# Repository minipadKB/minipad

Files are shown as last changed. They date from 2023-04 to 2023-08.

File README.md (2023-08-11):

<div align="center">

# minipad






The PCB and case files for the minipad, an RP2040-based 2-3-key keypad for the rhythm game osu!.

This hardware is designed specifically to work with our open-source firmware,</br>
which can be found in our GitHub repository [here](https://github.com/minipadkb/minipad-firmware).

</div>

<div align="center">
<i>Made with ❤️ by Project Minipad</i>
</div>

# Which file should I download?

Head over to the [releases section](https://github.com/minipadKB/minipad/releases/latest). There, you can find the latest release and it's `Case.zip` and `PCB.zip` files. Download and extract them and you'll see a `2k` and `3k` folder in each archive. Depending on your desired amount of keys, use the files in that folder.

# Project Structure

The root folder of this repository is split into two folders, `Latest` and `Older Versions`. It is advised to only use the latest files.</br>
`Latest` contains the files for the newest version of the minipad PCB and Case.</br>
`Older Versions` contains a number of folders representing older releases of the PCBs and Cases.

Inside each versions folder you can find a `PCB` folder, containing a `2k` and `3k` folder for the two variants of the keypad, and a `Case` folder, containing the .stl files for the 3D-print.

If you are unsure about what to do or you're having any questions, feel free to join our [Discord](https://discord.gg/minipad)!

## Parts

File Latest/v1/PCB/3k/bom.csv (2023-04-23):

Comment | Designator | Footprint | LCSC
1k | R1,R4,R7 | R_0402_1005Metric | C11702
500mA | F1 | Fuse_0402_1005Metric | C136320
100nF | C11,C12,C13,C14,C15,C16,C17,C5,C7,C8 | C_0402_1005Metric | C1525
10uF | C9 | C_0402_1005Metric | C15525
20pF | C3,C4 | C_0402_1005Metric | C1554
USB_C_12P | USB1 | USB_C_Receptacle_HRO_TYPE-C-31-M-12 | C165948
RP2040 | U1 | RP2040-QFN-56 | C2040
27 | R2,R3 | R_0603_1608Metric | C25190
5.1k | R5,R6 | R_0402_1005Metric | C25905
Hall_Sensor | K1,K2,K3 | SOT-23 | C2904393
1uF | C1,C10,C2,C6 | C_0402_1005Metric | C52923
XC6206PxxxMR | U3 | SOT-23 | C5446
SRV05-4 | U2 | SOT-23-6-routable | C85364
12MHZ | Y1 | Crystal_SMD_3225-4Pin_3.2x2.5mm | C9002
W25Q128JVS | U4 | SOIC-8_5.23x5.23mm_P1.27mm | C97521

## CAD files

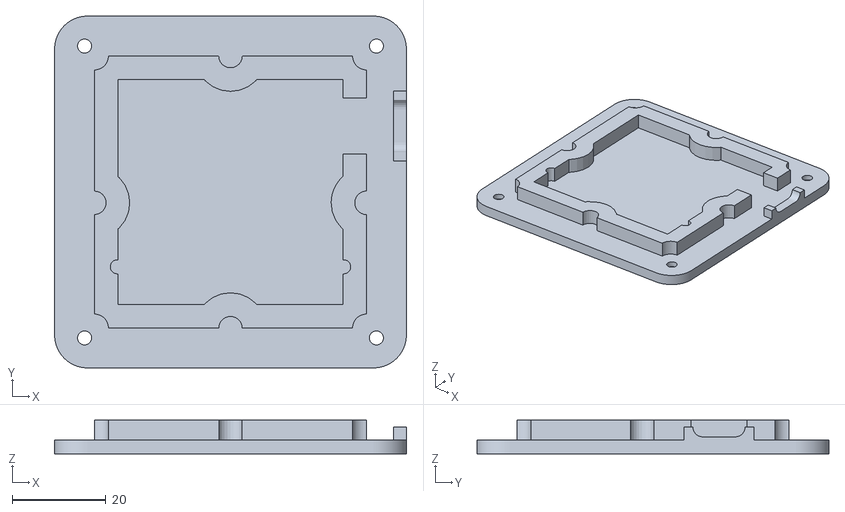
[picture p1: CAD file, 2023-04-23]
Latest/v1/Case/3k/bottom.stl
75.0 x 75.0 x 7.20

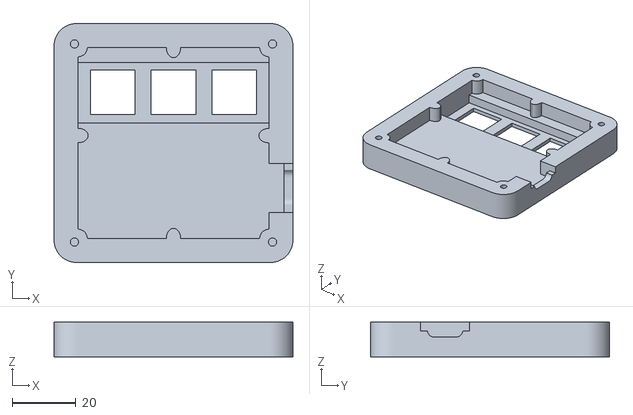
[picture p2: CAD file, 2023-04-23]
Latest/v1/Case/3k/top.stl
75.0 x 75.0 x 10.9

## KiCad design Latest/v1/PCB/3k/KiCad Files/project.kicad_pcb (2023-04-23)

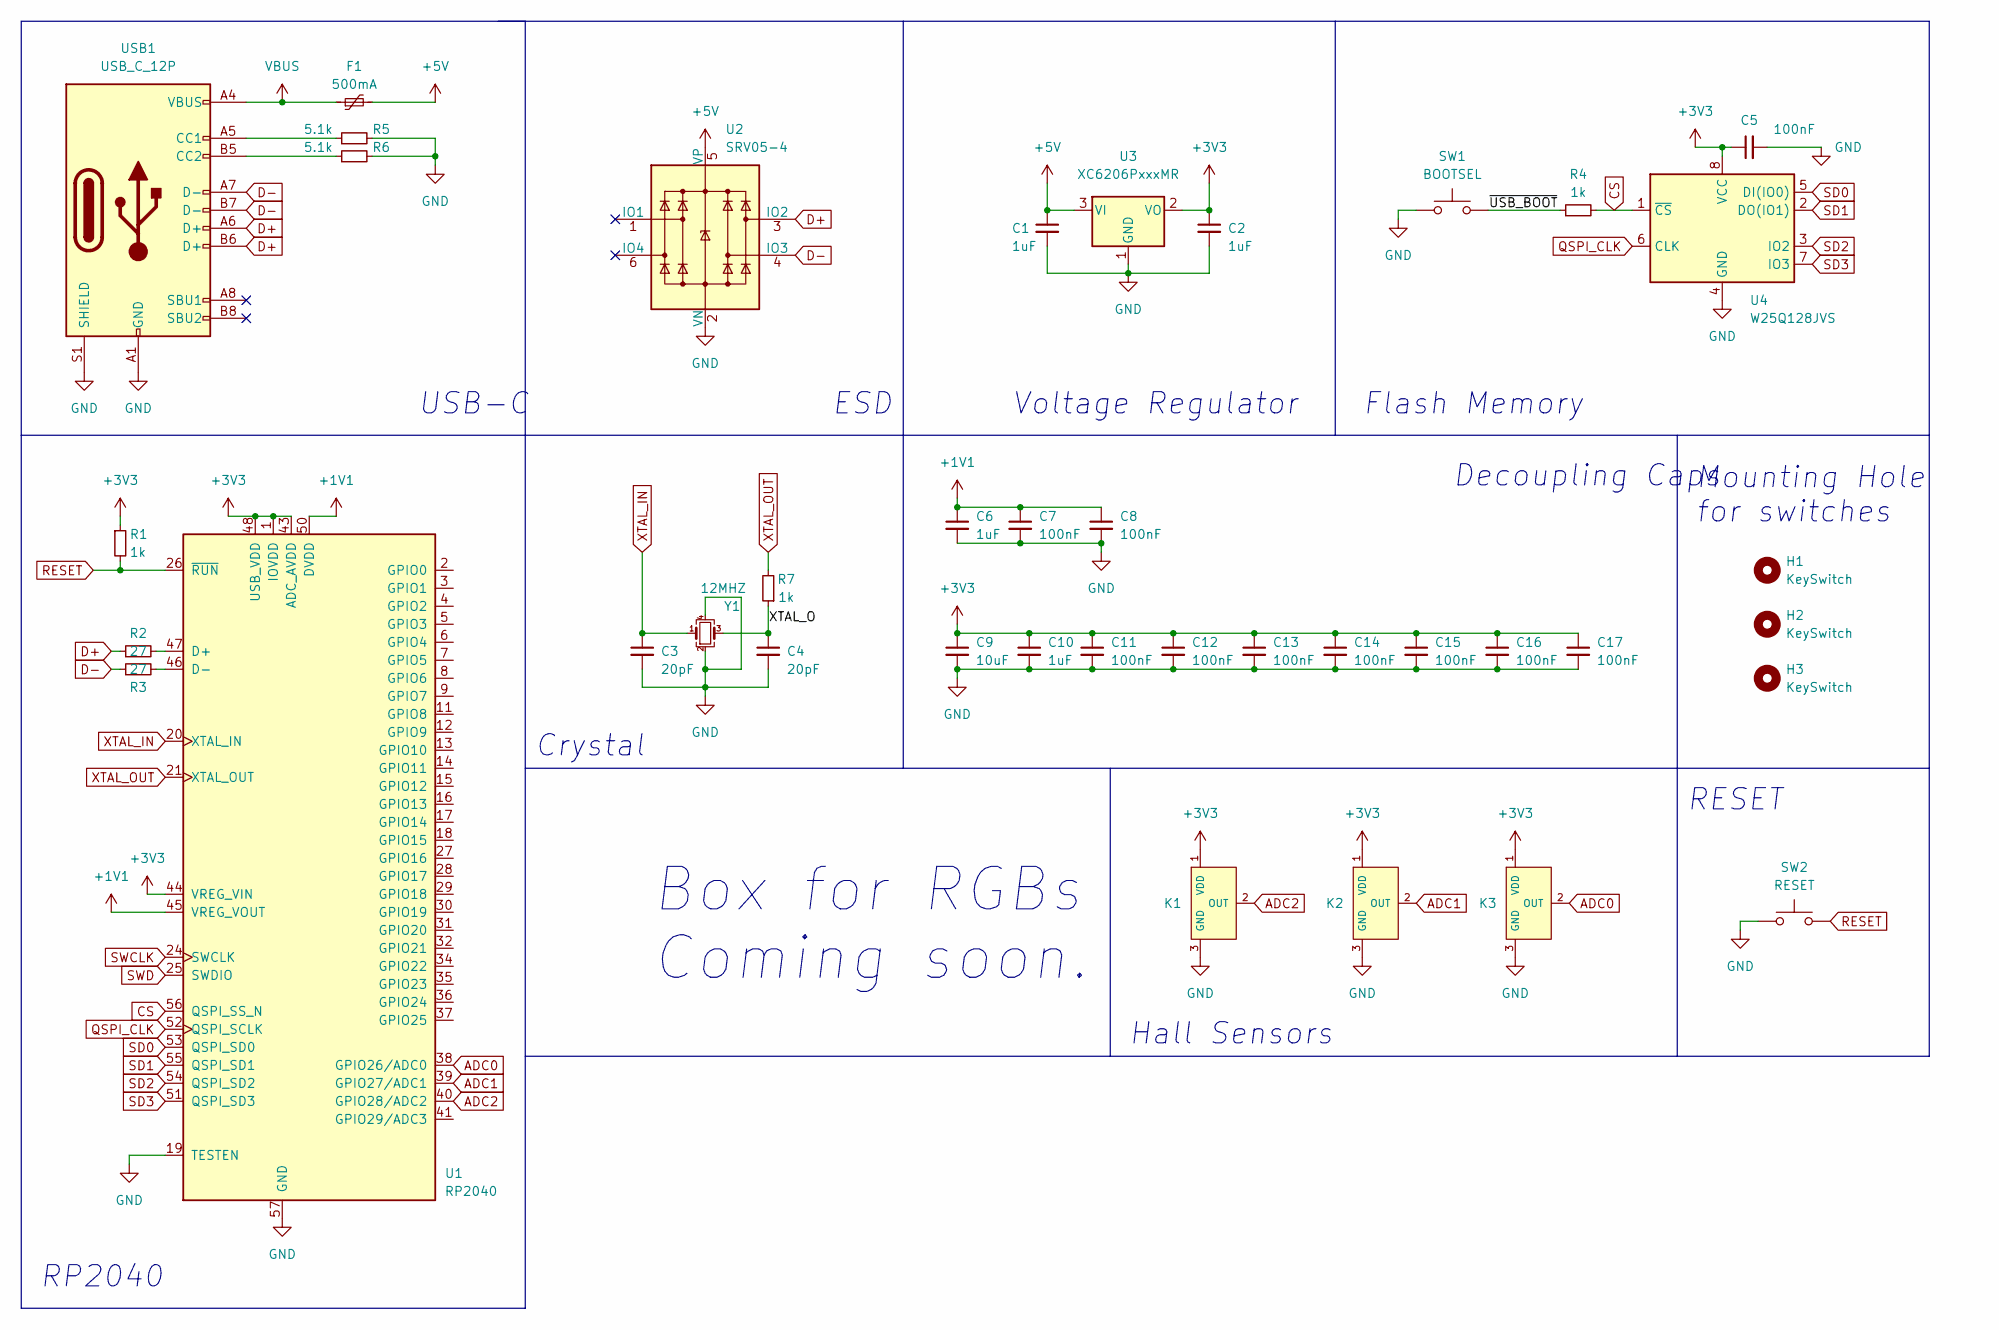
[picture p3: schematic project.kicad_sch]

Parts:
C1, C2, C6, C10: 1uF; C_0402_1005Metric
C3, C4: 20pF; C_0402_1005Metric
C5, C7, C8, C11, C12, C13, C14, C15, C16, C17: 100nF; C_0402_1005Metric
C9: 10uF; C_0402_1005Metric
F1: 500mA; Fuse_0402_1005Metric
H1, H2, H3: KeySwitch; MXOnly-1U-FLIPPED
K1, K2, K3: Hall_Sensor; SOT-23; MPN GH39FKSW; LCSC Part C266230
R1, R4, R7: 1k; R_0402_1005Metric
R2, R3: 27; R_0603_1608Metric
R5, R6: 5.1k; R_0402_1005Metric
SW1: BOOTSEL; SolderJumper-2_P1.3mm_Open_RoundedPad1.0x1.5mm
SW2: RESET; SolderJumper-2_P1.3mm_Open_RoundedPad1.0x1.5mm
U1: RP2040; RP2040-QFN-56
U2: SRV05-4; SOT-23-6-routable
U3: XC6206PxxxMR; SOT-23
U4: W25Q128JVS; SOIC-8_5.23x5.23mm_P1.27mm
USB1: USB_C_12P; USB_C_Receptacle_HRO_TYPE-C-31-M-12
Y1: 12MHZ; Crystal_SMD_3225-4Pin_3.2x2.5mm

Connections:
+1V1: C6.1, C7.1, C8.1, U1.23 (DVDD), U1.45 (VREG_VOUT), U1.50 (DVDD)
+3V3: C2.1, C5.1, C9.1, C10.1, C11.1, C12.1, C13.1, C14.1, C15.1, C16.1, C17.1, K1.1 (VDD), K2.1 (VDD), K3.1 (VDD), R1.1, U1.1 (IOVDD), U1.10 (IOVDD), U1.22 (IOVDD), U1.33 (IOVDD), U1.42 (IOVDD), U1.43 (ADC_AVDD), U1.44 (VREG_VIN), U1.48 (USB_VDD), U1.49 (IOVDD), U3.2 (VO), U4.8 (VCC)
+5V: C1.1, F1.2, U2.5 (VP), U3.3 (VI)
/XTAL_O: C4.1, R7.1, Y1.3
/~USB_BOOT: R4.1, SW1.2
ADC0: K3.2 (OUT), U1.38 (GPIO26/ADC0)
ADC1: K2.2 (OUT), U1.39 (GPIO27/ADC1)
ADC2: K1.2 (OUT), U1.40 (GPIO28/ADC2)
CS: R4.2, U1.56 (QSPI_SS_N), U4.1 (~CS)
D+: R2.1, U2.3 (IO2), USB1.A6 (D+), USB1.B6 (D+)
D-: R3.1, U2.4 (IO3), USB1.A7 (D-), USB1.B7 (D-)
GND: C1.2, C2.2, C3.2, C4.2, C5.2, C6.2, C7.2, C8.2, C9.2, C10.2, C11.2, C12.2, C13.2, C14.2, C15.2, C16.2, C17.2, K1.3 (GND), K2.3 (GND), K3.3 (GND), R5.2, R6.2, SW1.1, SW2.1, U1.19 (TESTEN), U1.57 (GND), U2.2 (VN), U3.1 (GND), U4.4 (GND), USB1.A1 (GND), USB1.A12 (GND), USB1.B1 (GND), USB1.B12 (GND), USB1.S1 (SHIELD), Y1.2, Y1.4
unnamed: R2.2, U1.47 (D+)
unnamed: R3.2, U1.46 (D-)
unnamed: R5.1, USB1.A5 (CC1)
unnamed: R6.1, USB1.B5 (CC2)
QSPI_CLK: U1.52 (QSPI_SCLK), U4.6 (CLK)
RESET: R1.2, SW2.2, U1.26 (~RUN)
RGB: U1.41 (GPIO29/ADC3)
SD0: U1.53 (QSPI_SD0), U4.5 (DI(IO0))
SD1: U1.55 (QSPI_SD1), U4.2 (DO(IO1))
SD2: U1.54 (QSPI_SD2), U4.3 (IO2)
SD3: U1.51 (QSPI_SD3), U4.7 (IO3)
SWCLK: U1.24 (SWCLK)
SWD: U1.25 (SWDIO)
VBUS: F1.1, USB1.A4 (VBUS), USB1.A9 (VBUS), USB1.B4 (VBUS), USB1.B9 (VBUS)
XTAL_IN: C3.1, U1.20 (XTAL_IN), Y1.1
XTAL_OUT: R7.2, U1.21 (XTAL_OUT)

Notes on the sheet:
Decoupling Caps
RESET
Box for RGBs Coming soon.
Voltage Regulator
ESD
RP2040
Hall Sensors
USB-C
Mounting Hole for switches
Crystal
Flash Memory

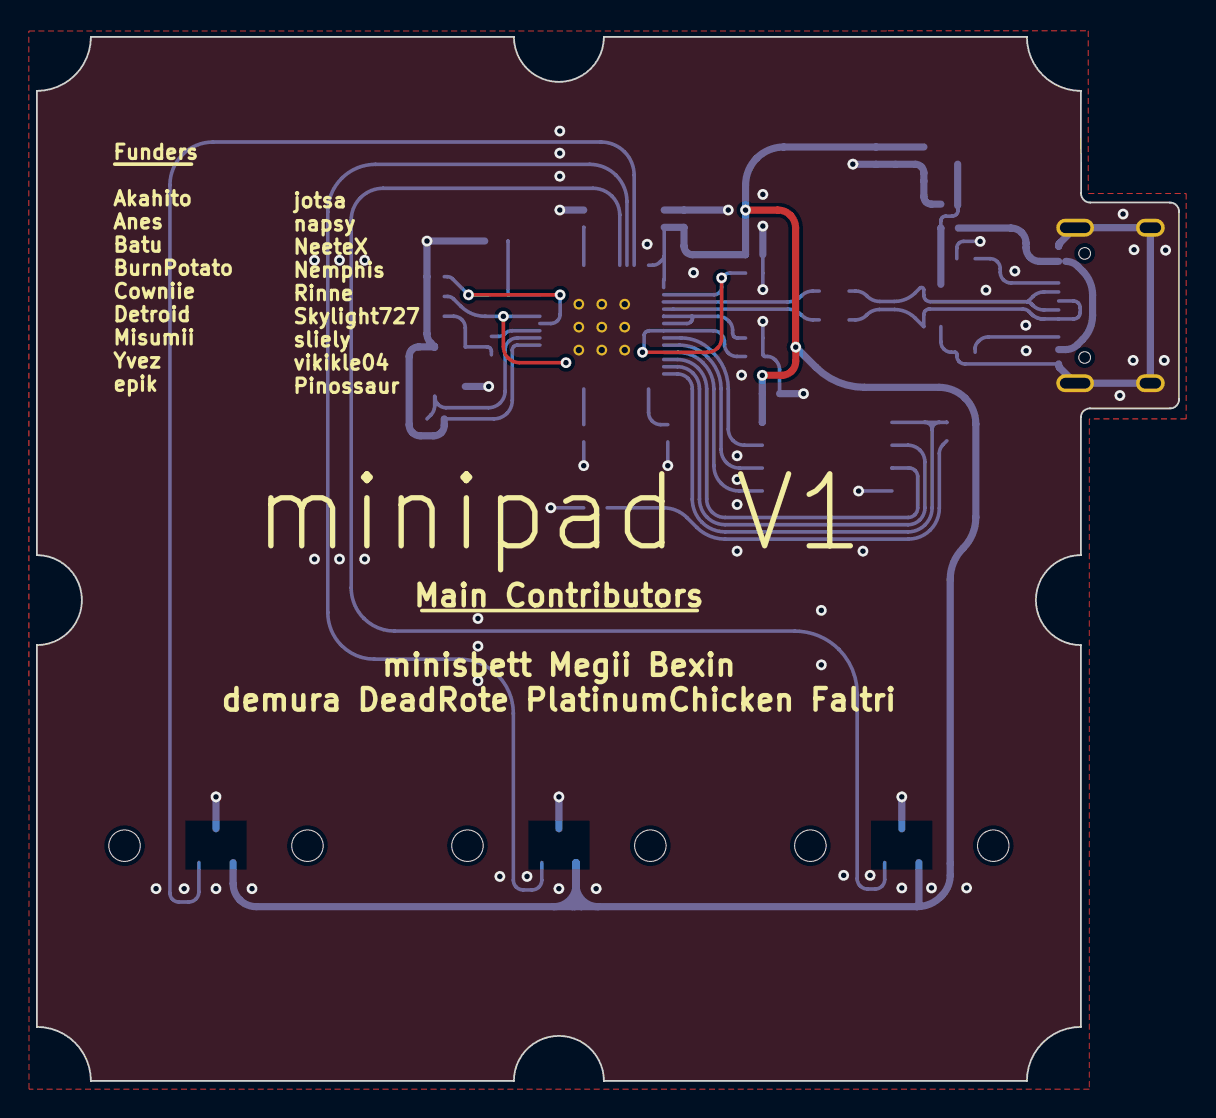
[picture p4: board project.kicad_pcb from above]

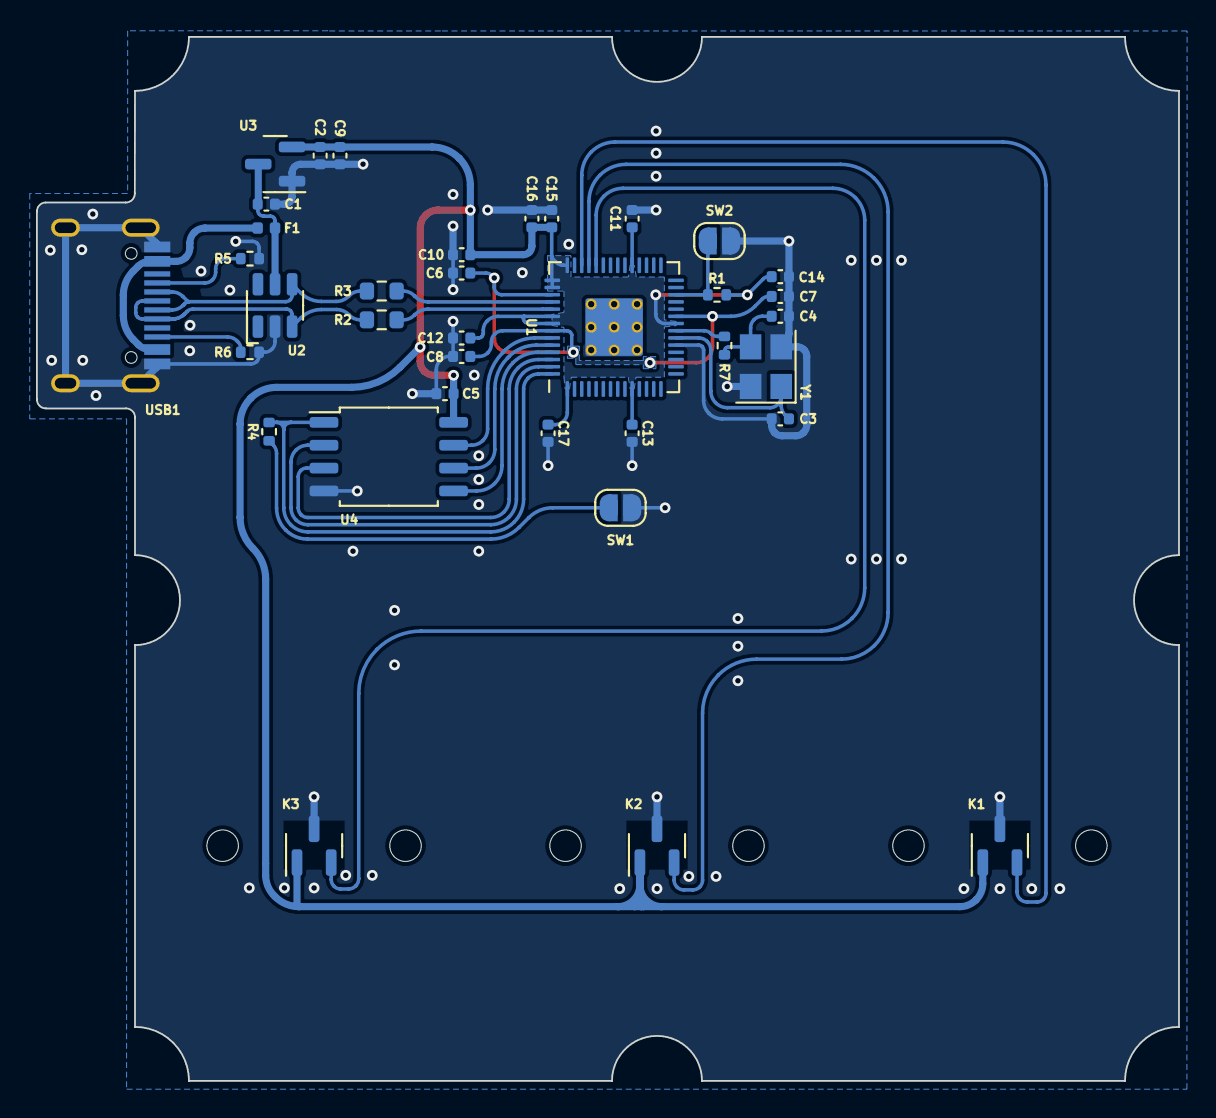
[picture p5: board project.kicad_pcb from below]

Board: 2 copper layers, 63.5 x 58.0 mm, 39 parts (39 on the bottom side), 25 nets.

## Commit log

2023-03-04 Create PCB
2023-04-23 Added V1 of case and PCB, added old Pro Micro PCB
    [bom.csv, bottom.stl, project.kicad_pcb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]
2023-04-23 Added KiCad project, updated gerber
    [pcb.kicad_pcb, project.kicad_pcb, schematic.kicad_sch]
2023-04-23 Move KiCad project to separate folder
    [project.kicad_sch, projectr.kicad_pcb]
2023-04-23 Rename pcb file
    [project.kicad_pcb]
2023-04-23 Add libraries
    [project.kicad_sch]
2023-04-23 Day 1 patch: Fix component placement
    [cpl.csv]
2023-08-11 Restructed repository
    [bom.csv, bottom.stl, project.kicad_pcb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]
2023-08-11 Put case files into 3k folder
    [bottom.stl, top.stl]

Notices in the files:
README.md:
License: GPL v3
